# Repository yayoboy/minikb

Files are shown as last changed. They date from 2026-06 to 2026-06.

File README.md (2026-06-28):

<div align="center">

# minikb

**Micro-tastiera meccanica 5×11 basata su RP2040 — USB HID + slave I2C compatibile CardKB**

55 tasti · NKRO · doppia interfaccia · LED di stato WS2812

`RP2040` · `USB HID` · `I2C 0x5F` · `Pico SDK` · `KMK` · `QMK`

</div>

---

## Indice

- [Panoramica](#panoramica)
- [Caratteristiche](#caratteristiche)
- [Hardware](#hardware)
  - [Specifiche](#specifiche)
  - [Pinout](#pinout)
- [Struttura del repository](#struttura-del-repository)
- [Firmware](#firmware)
  - [Confronto delle tre soluzioni](#confronto-delle-tre-soluzioni)
  - [Build e flash](#build-e-flash)
- [Interfaccia I2C (CardKB)](#interfaccia-i2c-cardkb)
- [Keymap](#keymap)
- [Documentazione](#documentazione)
- [Stato del progetto](#stato-del-progetto)
- [Roadmap / Open item](#roadmap--open-item)
- [Licenza](#licenza)

---

## Panoramica

`minikb` è una micro-tastiera meccanica con layout ortholineare **5×11 (55 tasti)**
costruita attorno al microcontrollore **Raspberry Pi RP2040**. È pensata per funzionare
in due modi, selezionati automaticamente:

1. **Tastiera USB HID** standard quando collegata via USB a un computer.
2. **Slave I2C compatibile CardKB** (M5Stack) quando collegata all'header I2C, così da
   sostituire in modo *drop-in* un modulo CardKB in progetti embedded esistenti
   (host che leggono 1 byte ASCII all'indirizzo `0x5F`).

Il repository contiene sia i **sorgenti hardware** (PCB EasyEDA Pro, Gerber, schematico)
sia il **firmware**, fornito in **tre implementazioni equivalenti** per permettere il
confronto tra basi tecnologiche differenti.

---

## Anteprima del layout

Layout minikb

> Centro = layer **BASE** · alto-destra (blu) = **Sym** · basso-destra (grigio) = **Fn**.
> Joystick integrato in basso a sinistra. Mappa modificabile da [`docs/keymap_editor.html`](docs/keymap_editor.html).

---

## Caratteristiche

- ⌨️ **55 tasti** in matrice 5×11 con **diodo per-tasto** → N-Key Rollover (NKRO).
- 🔌 **Doppia interfaccia**: USB HID e I2C slave, con selezione automatica della modalità.
- 🧩 **Compatibilità CardKB**: indirizzo `0x5F`, 1 byte ASCII per pressione.
- 🎚️ **Layer**: livello Base + livello **Fn** (frecce stile vim su I/J/K/L, F1–F12, media, navigazione).
- 🔊 **Tasti multimediali** (volume, play/pause, prev/next) via USB Consumer Control.
- 💡 **LED di stato WS2812** (indicatore Caps Lock / layer attivo).
- 🛠️ **Tre firmware**: Custom C (Pico SDK), KMK (CircuitPython), QMK.

---

## Hardware

### Specifiche

| Voce | Valore |
|---|---|
| Microcontrollore | RP2040 (dual Cortex-M0+, GPIO usati: GP0–GP21) |
| Layout | Ortholineare 5×11, 55 tasti |
| Matrice | 5 righe × 11 colonne, diodi D1–D55 (NKRO) |
| LED | 1 × WS2812 (indicatore di stato) |
| Connettività | USB (HID) + header I2C 1×4 (Grove/CardKB-like) |
| Alimentazione | 5V da USB → regolatore 3V3; oppure dall'header I2C |

### Pinout

Pin **confermati** dallo schematico (`SCH_Schematic1_1-P1_2026-06-20.svg`):

| Funzione | Net | GPIO |
|---|-----|---|
| Colonne 0–10 | `COL0..COL10` | **GP0 – GP10** |
| Righe 0–4 | `ROW0..ROW4` | **GP12 – GP16** |

Pin con **default da verificare** in EasyEDA Pro (vedi [`docs/pinout.md`](docs/pinout.md)):

| Funzione | GPIO default | Stato |
|---|---|---|
| I2C SDA | `GP20` | ⚠️ VERIFY |
| I2C SCL | `GP21` | ⚠️ VERIFY |
| WS2812 DIN | `GP28` | ✅ confermato |
| VBUS sense | `GP11` | ⚠️ VERIFY (opzionale) |

> I pin sono centralizzati in **un unico file di configurazione per firmware**, quindi
> un'eventuale correzione è una modifica di una riga.

---

## Struttura del repository

```
minikb/
├─ README.md                     · questo file
├─ minikb.epro2                  · progetto EasyEDA Pro (schema + PCB)
├─ SCH_Schematic1_*.svg          · export schematico
├─ silkscreen_aligned.jpg        · serigrafia (riferimento keymap)
├─ minikb(1)/                    · pacchetto di fabbricazione (Gerber + drill)
├─ docs/
│  ├─ pinout.md                  · pinout completo
│  ├─ keymap.md                  · layout + mappa ASCII CardKB
│  ├─ i2c-protocol.md            · protocollo I2C + esempi host
│  ├─ keymap_editor.html         · editor visuale della keymap
│  └─ keymap_layers.html         · vista dei layer
└─ minikb_fw_v1/                 · FIRMWARE FUNZIONANTE (PlatformIO/arduino-pico)
   ├─ src/main.cpp               · USB HID + 3 layer + joystick + LED + I2C CardKB
   ├─ platformio.ini             · build
   ├─ tools/                     · keymap_diag.py, it_layout_map.py
   └─ README.md                  · doc dettagliata del firmware
```

---

## Firmware

Il firmware funzionante, **collaudato su hardware**, è in [`minikb_fw_v1/`](minikb_fw_v1/)
(PlatformIO + arduino-pico/earlephilhower + TinyUSB). Implementa:

- Tastiera **USB HID** 5×11 con 3 layer (BASE / Fn / Sym) mappati per il layout host.
- **Joystick** TM-2028 → frecce + Invio.
- **Modalità mouse** (solo USB): Fn tenuto 2 s → joystick come mouse (cursore + click sx/dx); **Sym tenuto** → joystick = rotella, scroll verticale/orizzontale (v1.2).
- **LED di stato** WS2812 (mouse/Caps/Sym/Fn/Shift).
- **Slave I2C compatibile CardKB** (`0x5F`) — 1 byte ASCII per tasto, in parallelo all'USB.
  Implementato **a registri** (pico-sdk inline) e **collaudato con Meshtastic** su Heltec WiFi LoRa 32 V4 (v1.3).

### Build e flash

```bash
cd minikb_fw_v1
pio run                 # compila -> .pio/build/minikb/firmware.uf2
pio run -t upload       # flash (reset automatico 1200bps)
```

In alternativa copia `firmware.uf2` sull'RP2040 in modalità BOOTSEL (drive `RPI-RP2`).
Dettagli completi (pinout reale, layer, rimappatura, strumenti) nel
[README del firmware](minikb_fw_v1/README.md).

---

## Interfaccia I2C (CardKB)

Identica al M5Stack CardKB. Dettagli ed esempi in [`docs/i2c-protocol.md`](docs/i2c-protocol.md).

- **Indirizzo**: `0x5F` (7-bit)
- **Lettura master**: 1 byte → ASCII del tasto (`0x00` se nessuno)
- **Velocità**: 100 kHz / 400 kHz
- Caratteri **già risolti** (Shift/Fn applicati internamente)

```python
# Esempio host — Raspberry Pi (smbus2)
from smbus2 import SMBus, i2c_msg
with SMBus(1) as bus:
    msg = i2c_msg.read(0x5F, 1)
    bus.i2c_rdwr(msg)
    b = list(msg)[0]
    if b: print(chr(b))
```

---

## Keymap

Layout a due livelli (Base + Fn). Mappa completa e codici ASCII per il canale I2C in
[`docs/keymap.md`](docs/keymap.md).

```
Base
 Esc  1  2  3  4  5  6  7  8  9  Bksp
 Tab  Q  W  E  R  T  Y  U  I  O  P
 Caps A  S  D  F  G  H  J  K  L  Enter
 Sh   Z  X  C  V  B  N  M  ,  .  /
 Fn  Ctl Alt GUI Sym Spc ;  '  ←  ↓  ↑

Fn (raise): F1–F12 · frecce su I/J/K/L · media su Z/X/C/V · volume su W/S · Home/End/PgUp/PgDn
```

---

## Documentazione

| Documento | Contenuto |
|---|---|
| [`docs/pinout.md`](docs/pinout.md) | Pinout completo, pin da verificare, direzione diodi, auto-mode |
| [`docs/keymap.md`](docs/keymap.md) | Layout Base/Fn e tabella di conversione ASCII (CardKB) |
| [`docs/i2c-protocol.md`](docs/i2c-protocol.md) | Specifica I2C ed esempi host (Raspberry Pi, Arduino/ESP32) |

---

## Stato del progetto

| Componente | Stato |
|---|---|
| Hardware (PCB, Gerber, schematico) | ✅ completo |
| Firmware `minikb_fw_v1` — tastiera USB HID | ✅ compilato e collaudato su hardware |
| Firmware `minikb_fw_v1` — joystick + LED | ✅ collaudati su hardware |
| Firmware `minikb_fw_v1` — modalità mouse (v1.1) | ✅ collaudata su hardware |
| Firmware `minikb_fw_v1` — I2C CardKB (0x5F) | ✅ collaudato — rilevato da Meshtastic su Heltec WiFi LoRa 32 V4 (v1.3) |

---

## Roadmap / Open item

Verificato su hardware reale (test MicroPython, giugno 2026 — dettagli in [`docs/pinout.md`](docs/pinout.md)):

- [x] **Matrice** GP0–GP10 / GP12–GP16 — 28 tasti letti correttamente.
- [x] **I2C** SDA=GP20, SCL=GP21 — pull-up esterni rilevati.
- [x] **WS2812 DIN = GP28** — accensione confermata su hardware (firmware Arduino, self-test R/G/B). GP29 non funziona.
- [x] **Direzione diodi = COL2ROW** — confermata con test direzionale.

Risolto inoltre (firmware `minikb_fw_v1`):
- [x] **Joystick TM-2028**: pinout reale verificato (UP=GP26, DOWN=GP29, LEFT=GP11, RIGHT=GP27, PUSH=GP22).
- [x] **Frecce CardKB** `0xB4`–`0xB7` confermate sulla doc M5.
- [x] **I2C CardKB collaudato** (v1.3): Meshtastic su **Heltec WiFi LoRa 32 V4** rileva la minikb come CardKB e ne legge i tasti. Richiesto lo slave I2C **a registri** (lo slave `Wire` di arduino-pico consegnava sempre `0x7F`).

Ancora da chiudere:

- [ ] Lettere accentate sul canale I2C (non entrano in 1 byte ASCII; disponibili solo via USB).

---

## Licenza

Da definire. Specificare una licenza prima della pubblicazione (es. MIT/Apache-2.0 per il
firmware, CERN-OHL o CC-BY-SA per l'hardware).

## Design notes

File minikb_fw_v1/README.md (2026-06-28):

# minikb — firmware v1.3

Firmware **collaudato su hardware** per la minikb: micro-tastiera ortholineare 5×11 su
**RP2040**, con joystick a 5 vie. Sviluppato in **PlatformIO** (core arduino-pico
earlephilhower + TinyUSB).

Una sola tastiera, tre interfacce in parallelo:

- ⌨️ **USB HID** — tastiera completa a 3 layer, mappata per il layout host **macOS "Italian - Pro"**.
- 🕹️ **Joystick** TM-2028 → frecce (USB) e, in **modalità mouse**, cursore + click (v1.1).
- 🔌 **Slave I2C compatibile M5Stack CardKB** (`0x5F`) — 1 byte ASCII per tasto. **Rilevata in automatico da Meshtastic** (collaudata su Heltec WiFi LoRa 32 V4, v1.3).
- 💡 **LED WS2812** di stato (Caps / Sym / Fn / Shift / mouse).

## Anteprima del layout

Layout minikb

> Centro di ogni tasto = layer **BASE** · in alto a destra (blu) = **Sym** · in basso a destra (grigio) = **Fn**.
> Tasti **Fn** (blu) e **Sym** (verde) nei colori del LED. Joystick integrato in basso a sinistra.

Mappa modificabile dall'editor visuale: [`docs/keymap_editor.html`](../docs/keymap_editor.html)
(esporta JSON, SVG e PNG stampabile).

---

## Hardware — pinout completo della board

Cosa è montato sulla board:

- **55 switch meccanici** (MX1–MX55) in matrice **5×11**, un **diodo per tasto** (COL2ROW) → NKRO.
- **Joystick a 5 vie TM-2028** (U2): 4 direzioni + pressione centrale, **comune a GND**.
- **LED RGB WS2812** (LED1) di stato, DIN via R1 300 Ω.
- **Header I2C 4 pin** (tipo CardKB/Grove): SDA, SCL, +V, GND.

Pinout RP2040 — tutti i pin **confermati su hardware**:

| GPIO | Collegato a | Note |
|---|---|---|
| GP0–GP10 | Matrice — **colonne** COL0..COL10 | input pull-up, lette |
| GP11 | Joystick **LEFT** | attivo-basso (comune GND) |
| GP12–GP16 | Matrice — **righe** ROW0..ROW4 | output, pilotate LOW a turno |
| GP17–GP19 | — liberi | |
| GP20 | **I2C SDA** (CardKB 0x5F) | |
| GP21 | **I2C SCL** (CardKB 0x5F) | |
| GP22 | Joystick **PUSH** (centro) | attivo-basso |
| GP23–GP25 | — liberi | |
| GP26 | Joystick **UP** | attivo-basso |
| GP27 | Joystick **RIGHT** | attivo-basso |
| GP28 | **LED WS2812 DIN** | via R1 300 Ω |
| GP29 | Joystick **DOWN** | attivo-basso |

- **Matrice**: diodi COL2ROW → scansione riga LOW, colonna LOW = tasto premuto.
- **Joystick**: comune a GND, ingressi pull-up interni, direzione premuta = LOW.

> Correzioni verificate a mano (la doc/schematico erano errati): il LED è su **GP28** (non GP29);
> il pinout del modulo joystick è **ruotato** → i valori qui sopra sono quelli reali sull'hardware.

---

## Layer

Layout host di riferimento: **macOS "Italian - Pro"**. I caratteri sono già tradutti nel
firmware (es. `;` = Shift+`,`, `@` = Option+ò, `{` = Shift+Option+è), così escono giusti
senza cambiare il layout del Mac.

- **BASE** — lettere, numeri, punteggiatura, Space, Bksp, Caps, Shift. Fn/Sym in basso a sinistra.
- **Fn** (tieni Fn) — F1–F12, media (Vol/Mute/Play/Prev/Next), PgUp/PgDn/Home/End, Del, PrtSc,
  e scorciatoie **⌘A / ⌘X / ⌘C / ⌘V** (Sel.tutto / Taglia / Copia / Incolla).
- **Sym** (tieni Sym) — **Esc**, simboli (`! " £ $ % & ( ) ?`, `@ # § { } ∞ ◊ + - * | < > ~`, `` ` ``),
  e i modificatori **Ctrl / Alt / GUI** su A / S / D.

**Joystick**: ↑ ↓ ← → + centro = Invio (PUSH).

**LED di stato** (spento a riposo): mouse = ciano · Caps = rosso · Sym = verde · Fn = blu · Shift = giallo.

---

## Modalità mouse (v1.1) — solo USB

Tieni **Fn da solo per 2 secondi** per attivare/disattivare la modalità mouse (il LED diventa **ciano**):

- **Cursore**: joystick, con **accelerazione** (preciso sui piccoli spostamenti, veloce sulle lunghe distanze).
- **Click sinistro**: PUSH (centro joystick).
- **Click destro**: **Sym + PUSH**.
- **Scroll** (v1.2): tieni **Sym** e usa il joystick come rotella — su/giù = scroll **verticale**, sx/dx = scroll **orizzontale**. Il cursore resta fermo mentre tieni Sym.
- La tastiera continua a scrivere normalmente.
- Esci tenendo di nuovo **Fn 2 s**.

> La modalità mouse riguarda **solo l'USB**. Sul canale I2C il joystick resta sempre frecce.

---

## I2C compatibile CardKB (0x5F)

Un host (Raspberry Pi, ESP32, …) su SDA=GP20 / SCL=GP21 legge **1 byte ASCII per tasto** all'indirizzo `0x5F`:

- Minuscole di default; **Shift** → maiuscole/simboli US; **Sym** → secondo valore.
- Speciali: Enter `0x0D`, Esc `0x1B`, Backspace `0x08`, Tab `0x09`, Del `0x7F`, Space `0x20`.
- Joystick → frecce CardKB: Left `0xB4`, Up `0xB5`, Down `0xB6`, Right `0xB7`, centro → Enter.
- `0x00` = nessun tasto (coda FIFO, 1 byte per read). ASCII **US puro**, indipendente dal layout.
- Senza equivalente CardKB → `0x00`: scorciatoie ⌘, modificatori, caratteri non-ASCII (`£ § ∞ ◊`).

```python
# host Raspberry Pi (smbus2)
from smbus2 import SMBus, i2c_msg
with SMBus(1) as bus:
    msg = i2c_msg.read(0x5F, 1); bus.i2c_rdwr(msg)
    b = list(msg)[0]
    if b: print(hex(b), chr(b) if 32 <= b < 127 else "")
```

> **Collaudato** con master esterno: una **Heltec WiFi LoRa 32 V4** con Meshtastic rileva la
> minikb come CardKB sul bus dell'OLED (SDA=GPIO17, SCL=GPIO18) e ne legge i tasti.
>
> **Nota implementativa (v1.3)**: lo slave I2C usa il blocco hardware **a registri**
> (`i2c_set_slave_mode` + IRQ su `I2C0_IRQ`, byte scritto con `i2c_write_byte_raw` sul `RD_REQ`),
> non lo slave del wrapper `Wire` di arduino-pico — che non consegnava i byte non-zero
> (il master leggeva sempre `0x7F`). La lib `pico_i2c_slave` non è esposta dal build
> arduino-pico, quindi l'handler è replicato inline in `src/main.cpp`.

---

## Build e flash

Richiede [PlatformIO](https://platformio.org/) (`pip install platformio`).

```bash
cd minikb_fw_v1
pio run                 # compila -> .pio/build/minikb/firmware.uf2
pio run -t upload       # flash (reset automatico 1200bps)
```

In alternativa copia `firmware.uf2` sull'RP2040 in modalità BOOTSEL (drive `RPI-RP2`).

---

## Rimappare i tasti

1. Apri [`docs/keymap_editor.html`](../docs/keymap_editor.html) nel browser.
2. Clicca una cella → scrivi un carattere, o clicca un **simbolo** / **funzione** / **scorciatoia**.
3. **Esporta JSON** (e, se vuoi, **SVG/PNG** stampabile).
4. Dal JSON si rigenera la `keymap[3][...]` in `src/main.cpp`; i caratteri si traducono al layout
   con `tools/it_layout_map.py` (stampa usage HID + Shift/Option per ogni carattere).

| File | A cosa serve |
|---|---|
| `docs/keymap_editor.html` | Editor visuale (layout fisico, joystick, simboli, export JSON/SVG/PNG) |
| `tools/it_layout_map.py` | Estrae da macOS la combinazione HID per ogni carattere del layout attivo |
| `tools/keymap_diag.py` | Probe seriale dei tasti (richiede un build con diagnostica) |

---

## Changelog

- **v1.3** — slave I2C CardKB **a registri** (pico-sdk inline) al posto del `Wire` di arduino-pico, che mandava sempre `0x7F`: ora il byte ASCII viene consegnato correttamente. CardKB **rilevata da Meshtastic** e collaudata su **Heltec WiFi LoRa 32 V4** (bus OLED SDA=GPIO17 / SCL=GPIO18; lo scan I2C avviene solo al boot).
- **v1.2** — scroll in modalità mouse: con **Sym** tenuto il joystick diventa rotella (scroll verticale e orizzontale, cursore fermo).
- **v1.1** — modalità mouse (joystick come mouse, Fn 2 s on/off; click sx = PUSH, dx = Sym+PUSH);
  layer Sym ampliato; editor con layout fisico, joystick integrato ed export SVG/PNG.
- **v1.0** — tastiera USB HID (3 layer, layout Italian-Pro, scorciatoie), joystick frecce,
  LED di stato, slave I2C CardKB.

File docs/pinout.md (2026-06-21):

# minikb — Pinout RP2040

Matrice **5 righe × 11 colonne = 55 tasti**, diodo per-tasto (D1–D55) → NKRO.

## Pin confermati (estratti dallo schematico `SCH_Schematic1_1-P1_2026-06-20.svg`)

| Funzione | Net | GPIO |
|---|---|---|
| Colonna 0..10 | COL0..COL10 | **GP0 .. GP10** |
| Riga 0..4 | ROW0..ROW4  | **GP12 .. GP16** |

L'RP2040 usa GP0–GP21 per matrice/I2C; inoltre **GP28** è cablato al LED WS2812 (DIN via R1 300Ω).

## Pin confermati su hardware reale (test MicroPython, giugno 2026)

> Verificati direttamente sulla board: matrice via rilevamento pressioni, LED accendendolo,
> I2C dai pull-up esterni rilevati e dal net `SCL0` nello schematico.

| Funzione | GPIO | Come confermato |
|---|---|---|
| I2C SDA  | **GP20** | pull-up 4.7k rilevato; adiacente a SCL |
| I2C SCL  | **GP21** | net `SCL0` nello schematico; pull-up rilevato |
| LED WS2812 DIN | **GP28** | confermato su hardware (firmware Arduino, giugno 2026): self-test R/G/B su GP28 acceso. NB: GP29 non funziona |
| VBUS sense | **GP11** | da confermare; l'auto-mode usa di default l'enumerazione USB |

> Anche GP19 risulta tirato alto da un pull-up esterno (oltre a GP20/21): probabile terza
> linea del connettore I2C o un segnale ausiliario — non necessaria al firmware.

## Direzione diodi — CONFERMATA: COL2ROW

Verificato su hardware (test direzionale, giugno 2026): pilotando le **colonne** alte si
leggono alte le **righe** (2457 rilevazioni vs 0 nell'altro verso) → anodo sulla colonna,
conduzione **colonna → riga** = **COL2ROW** (convenzione QMK).

Per la scansione attiva-bassa del firmware: si pilotano le **righe** e si leggono le **colonne**.
Impostazioni: QMK `"diode_direction": "COL2ROW"`, KMK `DiodeOrientation.COL2ROW`,
Custom C `DIODE_COL2ROW 1`.

## Auto-mode USB / I2C

Primario (nessuna dipendenza da pin incerti): si inizializza lo stack USB e si attende
`tud_mounted()` per ~1 s. Se enumerato → **modalità USB HID**; altrimenti → **modalità slave I2C 0x5F**.
Opzionale: leggere VBUS-sense (GP11) come discriminante hardware (flag di compilazione).

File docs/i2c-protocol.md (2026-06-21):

# minikb — Protocollo I2C (compatibile CardKB)

## Scommario

- **Ruolo**: slave / target I2C.
- **Indirizzo**: `0x5F` (7-bit), identico al M5Stack CardKB.
- **Velocità**: 100 kHz (standard) e 400 kHz (fast) supportati.
- **Lettura master**: il master esegue una read di **1 byte**.
  - `0x00` → nessun tasto premuto dall'ultima lettura.
  - altrimenti → codice ASCII (o codice speciale) del tasto.

## Semantica

Identica a CardKB: il dispositivo mantiene **l'ultimo carattere** prodotto e lo restituisce
alla prossima read; dopo la read il buffer torna a `0x00` finché non viene premuto un nuovo tasto.
Il byte è **già risolto** (Shift/Fn applicati internamente), quindi l'host riceve il carattere
finale, non la posizione fisica del tasto.

## Codici (vedi anche docs/keymap.md)

```
ASCII stampabili : 0x20–0x7E
Enter            : 0x0D
Esc              : 0x1B
Backspace        : 0x08
Tab              : 0x09
Frecce  L/U/D/R  : 0xB4 / 0xB5 / 0xB6 / 0xB7   (convenzione CardKB — VERIFICARE)
```

## Esempio host (Raspberry Pi / Linux, Python smbus2)

```python
from smbus2 import SMBus, i2c_msg
ADDR = 0x5F
with SMBus(1) as bus:
    while True:
        msg = i2c_msg.read(ADDR, 1)
        bus.i2c_rdwr(msg)
        b = list(msg)[0]
        if b:
            print(hex(b), repr(chr(b)) if 0x20 <= b < 0x7f else "")
```

## Esempio host (Arduino / ESP32)

```cpp
#include <Wire.h>
void setup() { Wire.begin(); Serial.begin(115200); }
void loop() {
  Wire.requestFrom(0x5F, 1);
  if (Wire.available()) {
    uint8_t b = Wire.read();
    if (b) Serial.println(b, HEX);
  }
  delay(10);
}
```

## Validazione drop-in

1. `i2cdetect -y 1` deve mostrare `0x5F`.
2. Confrontare i byte restituiti (lettere, numeri, frecce, enter) con quelli di un **CardKB reale**.
3. Verificare il comportamento "un carattere per pressione" (no autorepeat sul canale I2C, come CardKB).

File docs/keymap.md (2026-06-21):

# minikb — Keymap

Dalla serigrafia `silkscreen_aligned.jpg`. Matrice logica 5×11 (riga, colonna).
Posizioni vuote = `XXX` (no key in quella cella della matrice).

`Fn` = layer momentaneo (raise). `Sym` = layer simboli. `Shift/Ctrl/Alt/GUI` = modificatori.

## Layer 0 — BASE

```
Col:    0     1     2     3     4     5     6     7     8     9     10
R0:    Esc    1     2     3     4     5     6     7     8     9    Bksp
R1:    Tab    Q     W     E     R     T     Y     U     I     O     P
R2:    Caps   A     S     D     F     G     H     J     K     L    Enter
R3:    Shift  Z     X     C     V     B     N     M     ,     .     /
R4:    Fn     Ctrl  Alt   GUI   Sym  Space  ;     '    Left  Down  Up/Right
```

> Nota: la fila R4 ha meno legende fisiche dei 11 fori; le celle non popolate sono `XXX`.
> Le posizioni esatte di Sym/`;`/`'`/ScrUp/ScrDn vanno riconciliate con EasyEDA al primo flash.

## Layer 1 — Fn (raise)

```
Col:    0     1     2     3     4     5     6     7     8     9     10
R0:     `    F1    F2    F3    F4    F5    F6    F7    F8    F9    Del
R1:    F11    .   Vol+   .     .     .     .   PgUp   Up    .   PrtSc
R2:    F12    .   Vol-   .     .     .   Home  Left  Down  Right  .
R3:     .   Mute  Play  Prev  Next   .   End  PgDn   .     .     .
R4:     .     .     .     .     .     .     .     .     .     .     .
```

Frecce stile vim su **I/J/K/L** (↑ ← ↓ →). Media su **Z/X/C/V**. Volume su **W/S**.

## Mappa ASCII per I2C (CardKB)

In modalità I2C il firmware ritorna **1 byte ASCII già risolto** (applicati Shift/Fn).
Tasti senza ASCII (modificatori puri, media) → `0x00`.

| Tasto | byte | Tasto | byte |
|---|---|---|---|
| lettere a–z | 0x61–0x7A | A–Z (con Shift) | 0x41–0x5A |
| 0–9 | 0x30–0x39 | Space | 0x20 |
| Enter | 0x0D | Esc | 0x1B |
| Backspace | 0x08 | Tab | 0x09 |
| Left | 0xB4 | Up | 0xB5 |
| Down | 0xB6 | Right | 0xB7 |

> I codici frecce 0xB4–0xB7 seguono la convenzione M5 CardKB — **verificare sul datasheet
> ufficiale** e confrontare con un CardKB reale prima di dichiarare la compatibilità drop-in.

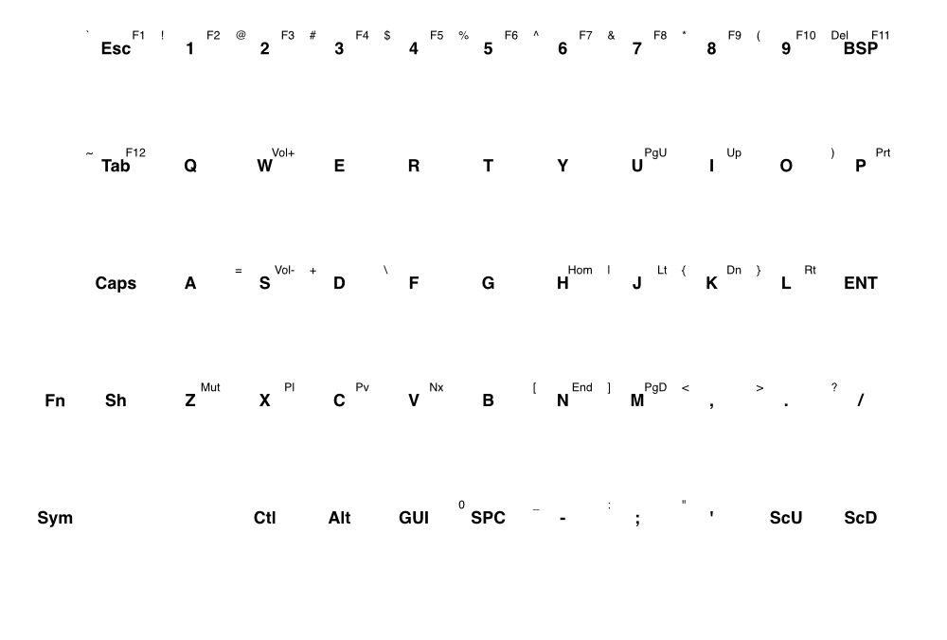
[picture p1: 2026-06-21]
silkscreen_aligned.jpg

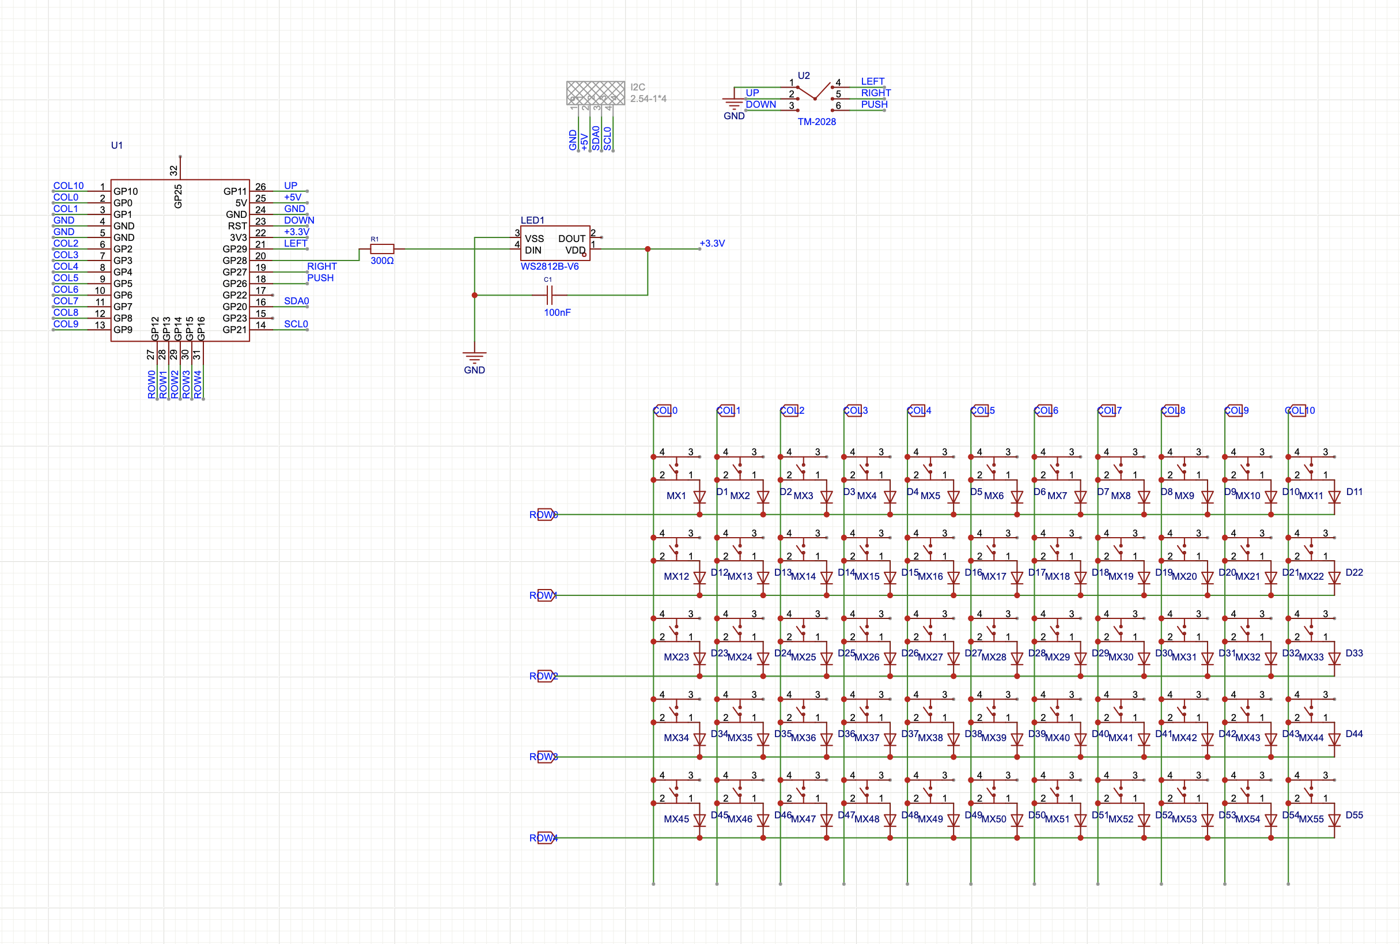
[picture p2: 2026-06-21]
Screenshot 2026-05-17 alle 15.57.12.png

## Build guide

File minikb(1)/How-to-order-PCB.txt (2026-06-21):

How to Order PCB

Please refer to:
https://prodocs.easyeda.com/en/pcb/order-order-pcb/index.html

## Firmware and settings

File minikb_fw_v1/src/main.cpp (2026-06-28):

// minikb — firmware v1.3 (PlatformIO / arduino-pico + TinyUSB).
// USB HID 5x11 (3 layer) + joystick (frecce / mouse) + media + LED stato WS2812 + I2C CardKB.
// v1.1: modalita' mouse (Fn tenuto 2s) -> joystick come mouse, solo USB.
// v1.2: in modalita' mouse, Sym tenuto -> joystick = rotella (scroll verticale + orizzontale).
// v1.3: slave I2C CardKB a registri (pico-sdk) -> fix consegna byte; lo slave 'Wire' di
//       arduino-pico mandava sempre 0x7F. CardKB ora rilevata da Meshtastic (Heltec V4).
//
// Hardware confermato:
//   Colonne COL0..COL10 = GP0..GP10   (lette, INPUT_PULLUP)
//   Righe   ROW0..ROW4  = GP12..GP16   (pilotate LOW una alla volta)
//   Diodi COL2ROW -> scansione: riga LOW, colonna LOW = tasto premuto.
//   LED WS2812 DIN = GP28 (confermato su hardware; schematico: -> R1 300ohm -> DIN LED1 WS2812B-V6).
//
// Slave I2C compatibile CardKB (0x5F) su SDA=GP20 / SCL=GP21: 1 byte ASCII per tasto.

#include <Arduino.h>
#include <Adafruit_TinyUSB.h>
#include <Adafruit_NeoPixel.h>
#include <hardware/i2c.h>
#include <hardware/gpio.h>
#include <hardware/irq.h>

// ---------------------------------------------------------------- pin hardware
static const uint8_t COL_PINS[] = {0, 1, 2, 3, 4, 5, 6, 7, 8, 9, 10}; // GP0..GP10
static const uint8_t ROW_PINS[] = {12, 13, 14, 15, 16};               // GP12..GP16
#define NCOLS 11
#define NROWS 5
#define LED_PIN 28

// Joystick digitale 5 vie TM-2028 (attivo-basso, comune GND).
// Mappa REALE verificata su hardware (il pinout del modulo era ruotato rispetto allo schematico):
// UP=GP26, DOWN=GP29, LEFT=GP11, RIGHT=GP27, PUSH=GP22.
#define NJOY 5
static const uint8_t  JOY_PINS[NJOY]   = {26, 29, 11, 27, 22};
static const uint8_t  JOY_ARROW[NJOY]  = {0x52, 0x51, 0x50, 0x4F, 0x28}; // Up,Down,Left,Right,Enter
static bool joyState[NJOY];

// ---------------------------------------------------------------- keymap encoding
// Ogni cella e' un uint16_t:
//   0x0000          = NO (cella matrice vuota)
//   0xFFFF          = TRNS (trasparente: ricade sul layer base)
//   0x4001          = FN  (layer momentaneo 1)
//   0x8000 | usage  = Consumer Control (media), usage = HID consumer usage
//   0x00..0xE7      = HID keyboard usage. 0xE0..0xE7 sono i modificatori.
#define NO   0x0000
#define TRNS 0xFFFF
#define FN   0x4001   // momentary -> layer 1 (Fn)
#define SYM  0x4002   // momentary -> layer 2 (Sym)
#define CONS(u) (0x8000 | (u))
// Usage con modificatore forzato (simboli IT + scorciatoie/combo).
// Bit di flag (combinabili) nei bit alti, usage HID nel byte basso:
#define F_SHIFT 0x2000
#define F_ALT   0x1000   // Option su Mac
#define F_CTRL  0x0400
#define F_GUI   0x0800   // Cmd su Mac
#define KS(u)  (F_SHIFT | (u))            // + Shift
#define KA(u)  (F_ALT   | (u))            // + Option
#define KSA(u) (F_SHIFT | F_ALT | (u))    // + Shift + Option
#define KG(u)  (F_GUI   | (u))            // + Cmd   (es. Cmd+C = copia)
#define KC_(u) (F_CTRL  | (u))            // + Ctrl

// HID consumer usages
#define CC_VOLUP  0x00E9
#define CC_VOLDN  0x00EA
#define CC_MUTE   0x00E2
#define CC_PLAY   0x00CD
#define CC_NEXT   0x00B5
#define CC_PREV   0x00B6

// Generato dall'editor (docs/keymap_editor.html), tradotto al layout macOS "Italian - Pro".
static const uint16_t keymap[3][NROWS * NCOLS] = {
  // Layer 0 — BASE
  {
    HID_KEY_1,   HID_KEY_2, HID_KEY_3, HID_KEY_4, HID_KEY_5, HID_KEY_6, HID_KEY_7, HID_KEY_8, HID_KEY_9, HID_KEY_0, HID_KEY_BACKSPACE,
    HID_KEY_TAB, HID_KEY_Q, HID_KEY_W, HID_KEY_E, HID_KEY_R, HID_KEY_T, HID_KEY_Y, HID_KEY_U, HID_KEY_I, HID_KEY_O, HID_KEY_P,
    HID_KEY_CAPS_LOCK, HID_KEY_A, HID_KEY_S, HID_KEY_D, HID_KEY_F, HID_KEY_G, HID_KEY_H, HID_KEY_J, HID_KEY_K, HID_KEY_L, HID_KEY_ENTER,
    HID_KEY_SHIFT_LEFT, HID_KEY_Z, HID_KEY_X, HID_KEY_C, HID_KEY_V, HID_KEY_B, HID_KEY_N, HID_KEY_M, HID_KEY_COMMA, HID_KEY_PERIOD, KS(0x24) /* / */,
    FN, SYM, KS(0x36) /* ; */, 0x2D /* ' */, 0x38 /* - */, HID_KEY_SPACE, HID_KEY_SHIFT_LEFT, KS(0x27) /* = */, KA(0x2F) /* [ */, KA(0x30) /* ] */, 0x64 /* \ */,
  },
  // Layer 1 — Fn (F-key, media, navigazione, scorciatoie taglia/copia/incolla)
  {
    HID_KEY_F1,  HID_KEY_F2, HID_KEY_F3, HID_KEY_F4, HID_KEY_F5, HID_KEY_F6, HID_KEY_F7, HID_KEY_F8, HID_KEY_F9, HID_KEY_F10, HID_KEY_DELETE,
    HID_KEY_F11, HID_KEY_F12, TRNS, TRNS, TRNS, TRNS, TRNS, HID_KEY_PAGE_UP, HID_KEY_HOME, TRNS, HID_KEY_PRINT_SCREEN,
    TRNS, TRNS, CONS(CC_VOLDN), CONS(CC_VOLUP), TRNS, TRNS, TRNS, HID_KEY_PAGE_DOWN, HID_KEY_END, TRNS, TRNS,
    TRNS, CONS(CC_MUTE), CONS(CC_PLAY), CONS(CC_PREV), CONS(CC_NEXT), TRNS, TRNS, TRNS, TRNS, TRNS, TRNS,
    FN, SYM, TRNS, TRNS, TRNS, TRNS, TRNS, KG(HID_KEY_A) /* Sel.tutto */, KG(HID_KEY_X) /* Taglia */, KG(HID_KEY_C) /* Copia */, KG(HID_KEY_V) /* Incolla */,
  },
  // Layer 2 — Sym (Esc, simboli, modificatori)
  {
    HID_KEY_ESCAPE, KS(0x1E) /* ! */, KS(0x1F) /* " */, KS(0x20) /* £ */, KS(0x21) /* $ */, KS(0x22) /* % */, KS(0x23) /* & */, KS(0x25) /* ( */, KS(0x26) /* ) */, KS(0x2D) /* ? */, HID_KEY_DELETE,
    KA(0x64) /* ` */, KA(0x33) /* @ */, KA(0x34) /* # */, KS(0x31) /* § */, KSA(0x2F) /* { */, KSA(0x30) /* } */, KA(0x0A) /* ∞ */, KSA(0x31) /* ◊ */, 0x30 /* + */, 0x38 /* - */, KS(0x30) /* * */,
    TRNS, HID_KEY_CONTROL_LEFT, HID_KEY_ALT_LEFT, HID_KEY_GUI_LEFT, KS(0x64) /* | */, 0x35 /* < */, KS(0x35) /* > */, KA(0x22) /* ~ */, TRNS, TRNS, TRNS,
    TRNS, TRNS, TRNS, TRNS, TRNS, TRNS, TRNS, TRNS, TRNS, TRNS, TRNS,
    FN, SYM, TRNS, TRNS, TRNS, TRNS, TRNS, TRNS, TRNS, TRNS, TRNS,
  },
};

// ---------------------------------------------------------------- USB HID
enum { RID_KEYBOARD = 1, RID_CONSUMER = 2, RID_MOUSE = 3 };
static const uint8_t desc_hid_report[] = {
  TUD_HID_REPORT_DESC_KEYBOARD(HID_REPORT_ID(RID_KEYBOARD)),
  TUD_HID_REPORT_DESC_CONSUMER(HID_REPORT_ID(RID_CONSUMER)),
  TUD_HID_REPORT_DESC_MOUSE(HID_REPORT_ID(RID_MOUSE)),
};
Adafruit_USBD_HID usb_hid;
static bool mouseMode = false;   // v1.1: joystick come mouse (Fn tenuto 2s on/off)

// ---------------------------------------------------------------- LED stato
Adafruit_NeoPixel led(1, LED_PIN, NEO_GRB + NEO_KHZ800);
static bool capsOn = false;

// Output report dall'host: bit0 = NumLock, bit1 = CapsLock, ...
static void hid_led_cb(uint8_t /*id*/, hid_report_type_t /*type*/, uint8_t const *buf, uint16_t len) {
  if (len < 1) return;
  capsOn = (buf[0] & 0x02) != 0;
}

// LED: modalita' mouse = ciano (priorita'); poi Caps/Sym/Fn/Shift. Spento altrimenti.
static void setStatusLed(bool fnActive, bool symActive, bool shiftHeld) {
  uint32_t c;
  if (mouseMode)      c = led.Color(0, 40, 50);  // ciano  = modalita' mouse
  else if (capsOn)    c = led.Color(60, 0, 0);   // rosso  = Caps Lock
  else if (symActive) c = led.Color(0, 40, 0);   // verde  = layer Sym
  else if (fnActive)  c = led.Color(0, 0, 60);   // blu    = layer Fn
  else if (shiftHeld) c = led.Color(50, 30, 0);  // giallo = Shift tenuto
  else                c = 0;                       // spento
  led.setPixelColor(0, c);
  led.show();
}

// ---------------------------------------------------------------- I2C CardKB (slave 0x5F)
// Canale ASCII separato dall'HID: il master legge 1 byte ASCII per tasto (0x00 = niente),
// frecce 0xB4-0xB7, Enter 0x0D, Esc 0x1B, Bksp 0x08, Tab 0x09, Del 0x7F.
// Le scorciatoie PC (Cmd/Ctrl) NON hanno equivalente CardKB -> byte 0x00 (ignorate).
#define I2C_ADDR 0x5F
#define I2C_SDA  20
#define I2C_SCL  21
#define I2C_INST i2c0   // GP20=SDA, GP21=SCL -> blocco I2C0 dell'RP2040

// Tabelle ASCII US (CardKB e' ASCII puro, indipendente dal layout host).
static const uint8_t ascii_base[NROWS*NCOLS] = {
  '1','2','3','4','5','6','7','8','9','0',0x08,
  0x09,'q','w','e','r','t','y','u','i','o','p',
  0,'a','s','d','f','g','h','j','k','l',0x0D,
  0,'z','x','c','v','b','n','m',',','.','/',
  0,0,';','\'','-',' ',0,'=','[',']','\\',
};
static const uint8_t ascii_shift[NROWS*NCOLS] = {
  '!','@','#','$','%','^','&','*','(',')',0x08,
  0x09,'Q','W','E','R','T','Y','U','I','O','P',
  0,'A','S','D','F','G','H','J','K','L',0x0D,
  0,'Z','X','C','V','B','N','M','<','>','?',
  0,0,':','"','_',' ',0,'+','{','}','|',
};
static const uint8_t ascii_sym[NROWS*NCOLS] = {
  0x1B,'!','"',0,'$','%','&','(',')','?',0x7F,    // £(idx3) non e' ASCII -> 0
  '`','@','#',0,'{','}',0,0,'+','-','*',          // §,∞,◊ non ASCII -> 0
  0,0,0,0,'|','<','>','~',0,0,0,                  // Ctrl/Alt/GUI -> nessun ASCII
  0,0,0,0,0,0,0,0,0,0,0,
  0,0,0,0,0,0,0,0,0,0,0,
};
static const uint8_t ascii_fn[NROWS*NCOLS] = {
  0,0,0,0,0,0,0,0,0,0,0x7F,                       // Fn = funzioni: solo Del ha un ASCII
  0,0,0,0,0,0,0,0,0,0,0,
  0,0,0,0,0,0,0,0,0,0,0,
  0,0,0,0,0,0,0,0,0,0,0,
  0,0,0,0,0,0,0,0,0,0,0,
};
// joystick -> codici CardKB: UP,DOWN,LEFT,RIGHT,PUSH
static const uint8_t JOY_I2C[NJOY] = {0xB5, 0xB6, 0xB4, 0xB7, 0x0D};

static uint8_t asciiFor(uint8_t layer, uint8_t idx, bool shift) {
  if (layer == 2) return ascii_sym[idx];
  if (layer == 1) return ascii_fn[idx];
  return shift ? ascii_shift[idx] : ascii_base[idx];
}

// coda come la CardKB: 1 byte per read, 0x00 se vuota
#define I2C_QSIZE 32
static volatile uint8_t i2cq[I2C_QSIZE];
static volatile uint8_t i2cqh = 0, i2cqt = 0;
static void i2cPush(uint8_t b) {
  if (!b) return;
  uint8_t n = (i2cqt + 1) % I2C_QSIZE;
  if (n == i2cqh) return;             // piena: scarta
  i2cq[i2cqt] = b; i2cqt = n;
}
// Slave I2C CardKB implementato a registri (la lib pico_i2c_slave NON e' esposta dal
// build arduino-pico). Gira in contesto IRQ sul blocco I2C0. Lo slave 'Wire' di
// arduino-pico corrompeva il byte trasmesso: il master leggeva sempre 0x7F invece
// dell'ASCII voluto (verificato sul log Meshtastic: ogni tasto -> kb 127). Qui sul
// RD_REQ scriviamo il byte DIRETTAMENTE nell'hardware, come una CardKB vera.
static void i2cSlaveIrq() {
  i2c_hw_t *hw = i2c_get_hw(I2C_INST);
  uint32_t stat = hw->intr_stat;
  if (stat == 0) return;
  if (stat & I2C_IC_INTR_STAT_R_TX_ABRT_BITS)   { hw->clr_tx_abrt; }
  if (stat & I2C_IC_INTR_STAT_R_START_DET_BITS) { hw->clr_start_det; }
  if (stat & I2C_IC_INTR_STAT_R_STOP_DET_BITS)  { hw->clr_stop_det; }
  if (stat & I2C_IC_INTR_STAT_R_RX_FULL_BITS) {
    (void)i2c_read_byte_raw(I2C_INST);          // CardKB non usa registri: scarta
  }
  if (stat & I2C_IC_INTR_STAT_R_RD_REQ_BITS) {
    hw->clr_rd_req;                             // il master legge: 1 byte dalla coda (0x00 se vuota)
    uint8_t b = 0;
    if (i2cqh != i2cqt) { b = i2cq[i2cqh]; i2cqh = (i2cqh + 1) % I2C_QSIZE; }
    i2c_write_byte_raw(I2C_INST, b);
  }
}

// ---------------------------------------------------------------- matrice
static bool state[NROWS][NCOLS];      // stato debounced
static uint8_t deb[NROWS][NCOLS];     // contatore debounce
#define DEBOUNCE 4

static void scanMatrix() {
  for (uint8_t r = 0; r < NROWS; r++) {
    pinMode(ROW_PINS[r], OUTPUT);
    digitalWrite(ROW_PINS[r], LOW);
    delayMicroseconds(8);             // assestamento
    for (uint8_t c = 0; c < NCOLS; c++) {
      bool pressed = (digitalRead(COL_PINS[c]) == LOW);
      if (pressed != state[r][c]) {
        if (++deb[r][c] >= DEBOUNCE) { state[r][c] = pressed; deb[r][c] = 0; }
      } else {
        deb[r][c] = 0;
      }
    }
    pinMode(ROW_PINS[r], INPUT);      // hi-Z: non disturba le altre righe
  }
}

static uint8_t joyDeb[NJOY];
static void scanJoystick() {
  for (uint8_t i = 0; i < NJOY; i++) {
    bool pressed = (digitalRead(JOY_PINS[i]) == LOW);
    if (pressed != joyState[i]) {
      if (++joyDeb[i] >= DEBOUNCE) { joyState[i] = pressed; joyDeb[i] = 0; }
    } else {
      joyDeb[i] = 0;
    }
  }
}

// ---------------------------------------------------------------- report build
static void buildAndSend() {
  // 1) layer attivo: Fn / Sym premuti? (Sym ha priorita'). Anche Shift fisico per il LED.
  bool fnActive = false, symActive = false, shiftHeld = false;
  for (uint8_t r = 0; r < NROWS; r++)
    for (uint8_t c = 0; c < NCOLS; c++)
      if (state[r][c]) {
        uint16_t b = keymap[0][r * NCOLS + c];
        if (b == FN)  fnActive = true;
        else if (b == SYM) symActive = true;
        else if (b == HID_KEY_SHIFT_LEFT || b == HID_KEY_SHIFT_RIGHT) shiftHeld = true;
      }
  uint8_t layer = symActive ? 2 : (fnActive ? 1 : 0);

  // conteggio tasti/joystick premuti (per il gesto Fn-da-solo)
  uint8_t pressedCount = 0;
  for (uint8_t r = 0; r < NROWS; r++)
    for (uint8_t c = 0; c < NCOLS; c++) if (state[r][c]) pressedCount++;
  bool joyAny = false;
  for (uint8_t i = 0; i < NJOY; i++) if (joyState[i]) joyAny = true;

  // v1.1: Fn tenuto da solo per 2s -> commuta modalita' mouse
  static uint32_t fnHoldStart = 0; static bool fnHoldDone = false;
  bool fnOnly = fnActive && pressedCount == 1 && !joyAny;
  if (fnOnly) {
    if (fnHoldStart == 0) fnHoldStart = millis();
    else if (!fnHoldDone && millis() - fnHoldStart >= 2000) { mouseMode = !mouseMode; fnHoldDone = true; }
  } else { fnHoldStart = 0; fnHoldDone = false; }

  uint8_t mods = 0;
  uint8_t kc[6] = {0};
  uint8_t nkc = 0;
  uint16_t consumer = 0;

  for (uint8_t r = 0; r < NROWS; r++) {
    for (uint8_t c = 0; c < NCOLS; c++) {
      if (!state[r][c]) continue;
      uint16_t v = keymap[layer][r * NCOLS + c];
      if (layer != 0 && v == TRNS) v = keymap[0][r * NCOLS + c]; // fall-through al base
      if (v == NO || v == TRNS || v == FN || v == SYM) continue;
      if (v & 0x8000) { consumer = v & 0x0FFF; continue; }     // media
      if (v & F_SHIFT) mods |= 0x02;                           // forza Shift
      if (v & F_ALT)   mods |= 0x04;                           // forza Option (LAlt)
      if (v & F_CTRL)  mods |= 0x01;                           // forza Ctrl
      if (v & F_GUI)   mods |= 0x08;                           // forza Cmd (LGui)
      uint8_t u = (uint8_t)v;
      if (u == 0) continue;
      if (u >= 0xE0 && u <= 0xE7) { mods |= (1 << (u - 0xE0)); continue; } // modificatore
      if (nkc < 6) kc[nkc++] = u;                              // tasto normale (6KRO)
    }
  }

  // joystick -> frecce (solo se NON in modalita' mouse)
  if (!mouseMode)
    for (uint8_t i = 0; i < NJOY; i++)
      if (joyState[i] && nkc < 6) kc[nkc++] = JOY_ARROW[i];

  // --- canale I2C CardKB: accoda 1 byte ASCII su ogni nuova pressione ---
  static bool i2cPrev[NROWS][NCOLS];
  for (uint8_t r = 0; r < NROWS; r++)
    for (uint8_t c = 0; c < NCOLS; c++) {
      bool now = state[r][c];
      if (now && !i2cPrev[r][c]) i2cPush(asciiFor(layer, r * NCOLS + c, shiftHeld));
      i2cPrev[r][c] = now;
    }
  // I2C CardKB: il joystick resta SEMPRE frecce (la modalita' mouse e' solo USB)
  static bool joyPrevI2C[NJOY];
  for (uint8_t i = 0; i < NJOY; i++) {
    if (joyState[i] && !joyPrevI2C[i]) i2cPush(JOY_I2C[i]);
    joyPrevI2C[i] = joyState[i];
  }

  static uint8_t lastMods = 0; static uint8_t lastKc[6] = {0};
  static uint16_t lastConsumer = 0;

  if (mods != lastMods || memcmp(kc, lastKc, 6) != 0) {
    if (usb_hid.ready()) {
      usb_hid.keyboardReport(RID_KEYBOARD, mods, kc);
      lastMods = mods; memcpy(lastKc, kc, 6);
    }
  }
  if (consumer != lastConsumer) {
    if (usb_hid.ready()) {
      usb_hid.sendReport16(RID_CONSUMER, consumer); // 0 = rilascio
      lastConsumer = consumer;
    }
  }

  // --- modalita' mouse (solo USB): joystick = cursore, PUSH = click, Sym = rotella ---
  //   Sym tenuto -> joystick = rotella: su/giu' = scroll V, sx/dx = scroll H (cursore fermo).
  if (mouseMode) {
    static uint32_t lastMs = 0; static int accel = 0; static uint8_t lastBtn = 0;
    static uint32_t lastScrollMs = 0; static int scrollAccel = 0;
    int dx = 0, dy = 0;
    if (joyState[2]) dx -= 1;   // LEFT
    if (joyState[3]) dx += 1;   // RIGHT
    if (joyState[0]) dy -= 1;   // UP
    if (joyState[1]) dy += 1;   // DOWN
    uint8_t btn = joyState[4] ? (symActive ? MOUSE_BUTTON_RIGHT : MOUSE_BUTTON_LEFT) : 0;
    uint32_t now = millis();

    if (symActive) {
      // Sym tenuto: rotella. Convenzione HID wheel: V positivo = su, H positivo = destra.
      accel = 0;
      int sv = 0, sh = 0;
      if (dy < 0) sv = 1; else if (dy > 0) sv = -1;   // UP -> su, DOWN -> giu'
      if (dx > 0) sh = 1; else if (dx < 0) sh = -1;   // RIGHT -> destra, LEFT -> sinistra
      if (sv || sh) {
        if (now - lastScrollMs >= 60 && usb_hid.ready()) {  // throttle: rotella piu' lenta del cursore
          lastScrollMs = now;
          if (scrollAccel < 36) scrollAccel++;
          int st = 1 + scrollAccel / 12; if (st > 3) st = 3; // lieve accelerazione (1..3 tacche)
          usb_hid.mouseReport(RID_MOUSE, btn, 0, 0, sv * st, sh * st);
          lastBtn = btn;
        }
      } else {
        scrollAccel = 0;
        if (btn != lastBtn) { usb_hid.mouseReport(RID_MOUSE, btn, 0, 0, 0, 0); lastBtn = btn; }
      }
    } else if (now - lastMs >= 8 && usb_hid.ready()) {
      scrollAccel = 0;
      lastMs = now;
      if (dx || dy) {
        if (accel < 48) accel++;
        int sp = 1 + accel / 6; if (sp > 9) sp = 9;     // accelerazione
        usb_hid.mouseReport(RID_MOUSE, btn, dx * sp, dy * sp, 0, 0);
        lastBtn = btn;
      } else {
        accel = 0;
        if (btn != lastBtn) { usb_hid.mouseReport(RID_MOUSE, btn, 0, 0, 0, 0); lastBtn = btn; }
      }
    }
  }

  setStatusLed(fnActive, symActive, shiftHeld);
}

// ---------------------------------------------------------------- setup / loop
void setup() {
  // --- USB HID PER PRIMA COSA: deve essere registrato prima che il core enumeri,
  //     altrimenti l'host enumera senza endpoint HID e usb_hid.ready() resta false.
  usb_hid.setPollInterval(2);
  usb_hid.setReportDescriptor(desc_hid_report, sizeof(desc_hid_report));
  usb_hid.setReportCallback(NULL, hid_led_cb);
  usb_hid.begin();
  // Se il core aveva gia' enumerato (warm reflash), forza la re-enumerazione con l'HID.
  if (TinyUSBDevice.mounted()) { TinyUSBDevice.detach(); delay(10); TinyUSBDevice.attach(); }

  // colonne in input pull-up
  for (uint8_t c = 0; c < NCOLS; c++) pinMode(COL_PINS[c], INPUT_PULLUP);
  // righe hi-Z a riposo
  for (uint8_t r = 0; r < NROWS; r++) pinMode(ROW_PINS[r], INPUT);
  // joystick: ingressi con pull-up (attivi-bassi, comune GND)
  for (uint8_t i = 0; i < NJOY; i++) pinMode(JOY_PINS[i], INPUT_PULLUP);

  // slave I2C CardKB su GP20/GP21 (I2C0), indirizzo 0x5F — slave mode + IRQ a registri.
  gpio_init(I2C_SDA); gpio_set_function(I2C_SDA, GPIO_FUNC_I2C); gpio_pull_up(I2C_SDA);
  gpio_init(I2C_SCL); gpio_set_function(I2C_SCL, GPIO_FUNC_I2C); gpio_pull_up(I2C_SCL);
  i2c_init(I2C_INST, 400 * 1000);
  i2c_set_slave_mode(I2C_INST, true, I2C_ADDR);
  i2c_get_hw(I2C_INST)->intr_mask =
      I2C_IC_INTR_MASK_M_RX_FULL_BITS | I2C_IC_INTR_MASK_M_RD_REQ_BITS |
      I2C_IC_INTR_MASK_M_TX_ABRT_BITS | I2C_IC_INTR_MASK_M_STOP_DET_BITS |
      I2C_IC_INTR_MASK_M_START_DET_BITS;
  irq_set_exclusive_handler(I2C0_IRQ, i2cSlaveIrq);
  irq_set_enabled(I2C0_IRQ, true);

  led.begin();
  led.setBrightness(255);
  // self-test LED all'avvio: R -> G -> B (conferma cablaggio GP28)
  const uint32_t boot[] = {led.Color(80,0,0), led.Color(0,80,0), led.Color(0,0,80)};
  for (uint8_t i = 0; i < 3; i++) { led.setPixelColor(0, boot[i]); led.show(); delay(180); }
  led.setPixelColor(0, 0); led.show();
}

void loop() {
  scanMatrix();
  scanJoystick();
  buildAndSend();
  delay(1);
}

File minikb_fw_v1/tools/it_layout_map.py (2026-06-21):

#!/usr/bin/env python3
"""Estrae dalla macOS attiva (layout corrente, es. 'Italian - Pro') la combinazione
HID necessaria a produrre ciascun carattere ASCII.

Per ogni virtual keycode + stato modificatori usa Carbon UCKeyTranslate per sapere
quale carattere esce, poi converte il virtual keycode in usage HID. Output: per ogni
carattere voluto, 'usage' HID e se serve Shift / Option (Alt su Mac).

Uso: python3 it_layout_map.py "; ' - = [ ] \\ / : _ @ # ( ) ? !"
(senza argomenti usa un set di default)
"""
import ctypes, ctypes.util, sys

# macOS virtual keycode -> HID usage (tabella fissa ANSI/ISO)
VK2HID = {
 0x00:0x04,0x01:0x16,0x02:0x07,0x03:0x09,0x04:0x0B,0x05:0x0A,0x06:0x1D,0x07:0x1B,
 0x08:0x06,0x09:0x19,0x0A:0x64,0x0B:0x05,0x0C:0x14,0x0D:0x1A,0x0E:0x08,0x0F:0x15,
 0x10:0x1C,0x11:0x17,0x12:0x1E,0x13:0x1F,0x14:0x20,0x15:0x21,0x16:0x23,0x17:0x22,
 0x18:0x2E,0x19:0x26,0x1A:0x24,0x1B:0x2D,0x1C:0x25,0x1D:0x27,0x1E:0x30,0x1F:0x12,
 0x20:0x18,0x21:0x2F,0x22:0x0C,0x23:0x13,0x24:0x28,0x25:0x0F,0x26:0x0D,0x27:0x34,
 0x28:0x0E,0x29:0x33,0x2A:0x31,0x2B:0x36,0x2C:0x38,0x2D:0x11,0x2E:0x10,0x2F:0x37,
 0x30:0x2B,0x31:0x2C,0x32:0x35,0x33:0x2A,0x35:0x29,
}

CF = ctypes.CDLL(ctypes.util.find_library("CoreFoundation"))
Carbon = ctypes.CDLL(ctypes.util.find_library("Carbon"))

CFDataGetBytePtr = CF.CFDataGetBytePtr
CFDataGetBytePtr.restype = ctypes.c_void_p
CFDataGetBytePtr.argtypes = [ctypes.c_void_p]

Carbon.TISCopyCurrentKeyboardLayoutInputSource.restype = ctypes.c_void_p
Carbon.TISGetInputSourceProperty.restype = ctypes.c_void_p
Carbon.TISGetInputSourceProperty.argtypes = [ctypes.c_void_p, ctypes.c_void_p]
Carbon.LMGetKbdType.restype = ctypes.c_uint8

kTISPropertyUnicodeKeyLayoutData = ctypes.c_void_p.in_dll(
    Carbon, "kTISPropertyUnicodeKeyLayoutData")

UCKeyTranslate = Carbon.UCKeyTranslate
UCKeyTranslate.argtypes = [
    ctypes.c_void_p, ctypes.c_uint16, ctypes.c_uint16, ctypes.c_uint32,
    ctypes.c_uint32, ctypes.c_uint32, ctypes.POINTER(ctypes.c_uint32),
    ctypes.c_ulong, ctypes.POINTER(ctypes.c_ulong),
    ctypes.POINTER(ctypes.c_uint16 * 4)]

def layout_ptr():
    src = Carbon.TISCopyCurrentKeyboardLayoutInputSource()
    data = Carbon.TISGetInputSourceProperty(src, kTISPropertyUnicodeKeyLayoutData)
    return CFDataGetBytePtr(data)

def translate(layout, vk, mod, kbd):
    dead = ctypes.c_uint32(0)
    n = ctypes.c_ulong(0)
    buf = (ctypes.c_uint16 * 4)()
    UCKeyTranslate(layout, vk, 0, mod, kbd, 1, ctypes.byref(dead), 4,
                   ctypes.byref(n), ctypes.byref(buf))
    if n.value >= 1 and buf[0] != 0:
        return chr(buf[0])
    return None

# modifierKeyState per UCKeyTranslate: shift=2, option=8
MODS = [(0, False, False), (2, True, False), (8, False, True), (10, True, True)]

def build_map():
    layout = layout_ptr()
    kbd = Carbon.LMGetKbdType()
    m = {}
    for vk in VK2HID:
        for mstate, shift, opt in MODS:
            ch = translate(layout, vk, mstate, kbd)
            if ch and ch not in m:   # primo trovato = combo piu' semplice
                m[ch] = (VK2HID[vk], shift, opt)
    return m

def main():
    chars = sys.argv[1] if len(sys.argv) > 1 else "; ' - = [ ] \\ / : _ ? ! @ # ( ) & % $ \" | { } < > ^ ~ ` * + ="
    wanted = [c for c in chars if not c.isspace()]
    m = build_map()
    print(f"{'char':>4}  {'HID':>5}  Shift  Option   -> macro firmware")
    for c in wanted:
        if c in m:
            u, sh, op = m[c]
            if sh and op: macro = f"KSA(0x{u:02X})"
            elif sh:      macro = f"KS(0x{u:02X})"
            elif op:      macro = f"KA(0x{u:02X})"
            else:         macro = f"0x{u:02X}"
            print(f"{c!r:>4}  0x{u:02X}   {str(sh):>5}  {str(op):>6}   {macro}")
        else:
            print(f"{c!r:>4}   ---  (non producibile su questo layout con Shift/Option)")

if __name__ == "__main__":
    main()

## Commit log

2026-06-21 minikb: hardware + firmware funzionante (minikb_fw_v1)
    Tastiera RP2040 5x11 + joystick TM-2028.
    Firmware PlatformIO/arduino-pico: USB HID (3 layer, layout Italian-Pro,
    scorciatoie), joystick frecce+Invio, LED di stato WS2812 (GP28),
    slave I2C compatibile CardKB (0x5F).
    Incluso hardware (Gerber, schematico, EasyEDA) e docs (editor keymap).
    [Drill_PTH_Through.DRL, Drill_PTH_Through_Via.DRL, Gerber_BoardOutlineLayer.GKO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]
2026-06-21 firmware: keymap aggiornata (simboli IT); editor: layout fisico + joystick integrato
    - Sym: ? § { } infinito lozenge + - * | < > ~ , mappati al layout Italian-Pro
    - editor: layout fisico 12 colonne con joystick nella griglia, Fn sopra Sym
    - editor: simboli cliccabili, export SVG/PNG con Fn/Sym in colore LED
    - fix: @ e # letterali non piu' confusi con i token funzione/combo
    [main.cpp]
2026-06-21 v1.1: modalità mouse + README con anteprima layout
    - firmware: modalità mouse (Fn 2s on/off, solo USB) — joystick=cursore con
    accelerazione, click sx=PUSH, dx=Sym+PUSH; I2C resta sempre frecce
    - README firmware riscritto (v1.1) con anteprima del layout (docs/keymap_layout.svg)
    - README principale: anteprima layout + voce modalità mouse
    - editor: DEFAULT allineato alla keymap attuale
2026-06-21 README: pinout completo della board e collegamenti
    Tabella GP0-GP29 con cosa e' collegato (matrice, joystick TM-2028, LED, I2C),
    incluse le correzioni hardware (LED GP28, pinout joystick ruotato).
2026-06-21 firmware: scroll in modalità mouse (v1.2)
    In modalità mouse, tenendo Sym il joystick diventa rotella:
    su/giù = scroll verticale, sx/dx = scroll orizzontale (cursore fermo).
    Throttle 60 ms con lieve accelerazione; PUSH e Sym+PUSH invariati.
    Layout tasti e keymap non toccati.
    Doc allineata: README root, README firmware (+changelog v1.2),
    docs/keymap_layers.html.
2026-06-28 firmware v1.3: slave I2C CardKB a registri (fix consegna byte)
    Lo slave I2C usava il wrapper Wire di arduino-pico, che non consegnava i byte non-zero sul bus: il master leggeva sempre 0x7F. Su Heltec WiFi LoRa 32 V4 + Meshtastic ogni tasto risultava 'kb 127' con freeze del nodo.
    Sostituito con uno slave I2C a registri (pattern pico-sdk, replicato inline perche pico/i2c_slave.h non e esposto dal build arduino-pico): i2c_set_slave_mode + IRQ su I2C0_IRQ, byte scritto con i2c_write_byte_raw sul RD_REQ. Logica tastiera/mouse/coda invariata.
    Collaudato: Meshtastic su Heltec V4 rileva la minikb come CardKB (bus OLED SDA=GPIO17/SCL=GPIO18) e legge i tasti correttamente. README aggiornati (root +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
    [main.cpp]
